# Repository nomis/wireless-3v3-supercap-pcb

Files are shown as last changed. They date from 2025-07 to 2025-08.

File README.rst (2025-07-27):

Wireless 3.3V Supercapacitor PCB
================================

Overview
--------

PCB to wirelessly power a 3.3V microcontroller circuit and charge a
supercapacitor so that it keeps running for at least an hour when taken off the
charging coil.

Dimensions: 88mm W × 40mm H

Usage
-----

This is a KiCad project.

Safety
------

There is a toggle switch to discharge the supercapacitor, which will take 14-16
minutes at 390mΩ (unverified). This process is limited by the current switching
capacity of the switch.

Schematics
----------

Root schematic

Power In
~~~~~~~~

Power in schematic

Charge
~~~~~~

Charge schematic

Power Out
~~~~~~~~~

Output power is supplied at 3.3V up to 3A, from a supercapacitor voltage range
of 0.5-2.7V.

Power out schematic

PCB
---

PCB

Components
----------

+---------------------+----------+--------------------------------------------------------------+
| Refs                | Quantity | Name                                                         |
+=====================+==========+==============================================================+
| C.C0                |     1    | 22pF 10% 16V X7R Capacitor, SMD 0805 (Metric 2012)           |
+---------------------+----------+--------------------------------------------------------------+
| C.C1, C.C6, C.10,   |     4    | 0.1µF 10% 16V X7R Capacitor, SMD 0805 (Metric 2012)          |
| C.C11               |          |                                                              |
+---------------------+----------+--------------------------------------------------------------+
| C.C4, C.C5, C.C7    |     3    | 1µF 10% 16V X7R Capacitor, SMD 0805 (Metric 2012)            |
+---------------------+----------+--------------------------------------------------------------+
| C.C8, C.C9, P.C1    |     3    | 10µF 10% 16V X7R Capacitor, SMD 0805 (Metric 2012)           |
+---------------------+----------+--------------------------------------------------------------+
| C.C12               |     1    | 15µF 10% 16V X7R Capacitor, SMD 0805 (Metric 2012)           |
+---------------------+----------+--------------------------------------------------------------+
| M.C1                |     1    | Tecate TPLH-2R7/800PS35X71 800F 2.7V Capacitor, Through Hole |
+---------------------+----------+--------------------------------------------------------------+
| P.C2, P.C2          |     2    | 22µF 10% 10V X7R Capacitor, SMD 1206 (Metric 3216)           |
+---------------------+----------+--------------------------------------------------------------+
| C.D1                |     1    | Diotec BAT54 30V 200mA Zener Diode, SOT-23-3                 |
+---------------------+----------+--------------------------------------------------------------+
| M.J1                |     1    | 1x05 Pin Header, Through Hole (2.54mm)                       |
+---------------------+----------+--------------------------------------------------------------+
| C.L1                |     1    | Bourns SRN5040-100M 10µH 20% 2.1A Power Inductor             |
+---------------------+----------+--------------------------------------------------------------+
| P.L1                |     1    | Bourns SRP1245A-1R0M 1µH 20% 29A Power Inductor              |
+---------------------+----------+--------------------------------------------------------------+
| C.Q4, C.Q5          |     2    | Vishay SiS412DN N-Channel 30V 12A MOSFET, PowerPAK 1212-8    |
+---------------------+----------+--------------------------------------------------------------+
| M.R2                |     1    | 1kΩ 1% 125mW Resistor, SMD 0805 (Metric 2012)                |
+---------------------+----------+--------------------------------------------------------------+
| C.R0                |     1    | 10mΩ 0.1% 1W Resistor, SMD 0805 (Metric 2012)                |
+---------------------+----------+--------------------------------------------------------------+
| C.R1                |     1    | 305kΩ 0.1% 125mW Resistor, SMD 0805 (Metric 2012)            |
+---------------------+----------+--------------------------------------------------------------+
| C.R2                |     1    | 86.6kΩ 0.1% 125mW Resistor, SMD 0805 (Metric 2012)           |
+---------------------+----------+--------------------------------------------------------------+
| C.R5                |     1    | 100Ω 0.1% 125mW Resistor, SMD 0805 (Metric 2012)             |
+---------------------+----------+--------------------------------------------------------------+
| C.R6                |     1    | 10Ω 1% 125mW Resistor, SMD 0805 (Metric 2012)                |
+---------------------+----------+--------------------------------------------------------------+
| C.R7                |     1    | 100kΩ 0.1% 125mW Resistor, SMD 0805 (Metric 2012)            |
+---------------------+----------+--------------------------------------------------------------+
| C.R8                |     1    | 11.1kΩ 0.1% 125mW Resistor, SMD 0805 (Metric 2012)           |
+---------------------+----------+--------------------------------------------------------------+
| P.R1                |     1    | 402kΩ 0.1% 125mW Resistor, SMD 0805 (Metric 2012)            |
+---------------------+----------+--------------------------------------------------------------+
| P.R2                |     1    | 88.7kΩ 0.1% 125mW Resistor, SMD 0805 (Metric 2012)           |
+---------------------+----------+--------------------------------------------------------------+
| P.R3, P.R4          |     2    | 10kΩ 1% 125mW Resistor, SMD 0805 (Metric 2012)               |
+---------------------+----------+--------------------------------------------------------------+
| M.SW1               |     1    | C&K E103SYZGE SPDT Toggle Switch 7.5A 125V                   |
+---------------------+----------+--------------------------------------------------------------+
| C.TH1               |     1    | 1x02 Pin Header, Through Hole (2.54mm)                       |
|                     |     1    | Semitec 103AT-4-70261 10kΩ 1% Thermistor                     |
+---------------------+----------+--------------------------------------------------------------+
| C.U1                |     1    | Texas Instruments BQ24640RVAR Super Capacitor Charger        |
+---------------------+----------+--------------------------------------------------------------+
| P.U1                |     1    | Texas Instruments TPS61022 8A Boost Converter, 0.5-5.5V      |
+---------------------+----------+--------------------------------------------------------------+
|                     |     1    | Vishay IWAS4832AEEB120KF1 Wireless Charging Receive Coil     |
+---------------------+----------+--------------------------------------------------------------+

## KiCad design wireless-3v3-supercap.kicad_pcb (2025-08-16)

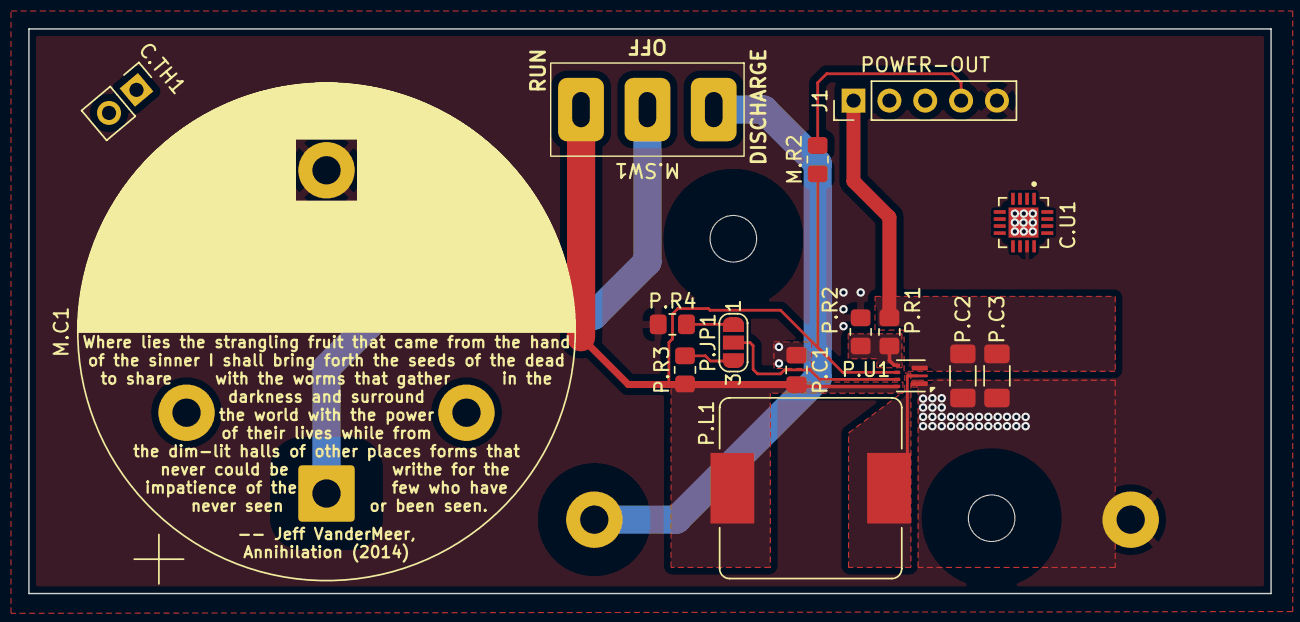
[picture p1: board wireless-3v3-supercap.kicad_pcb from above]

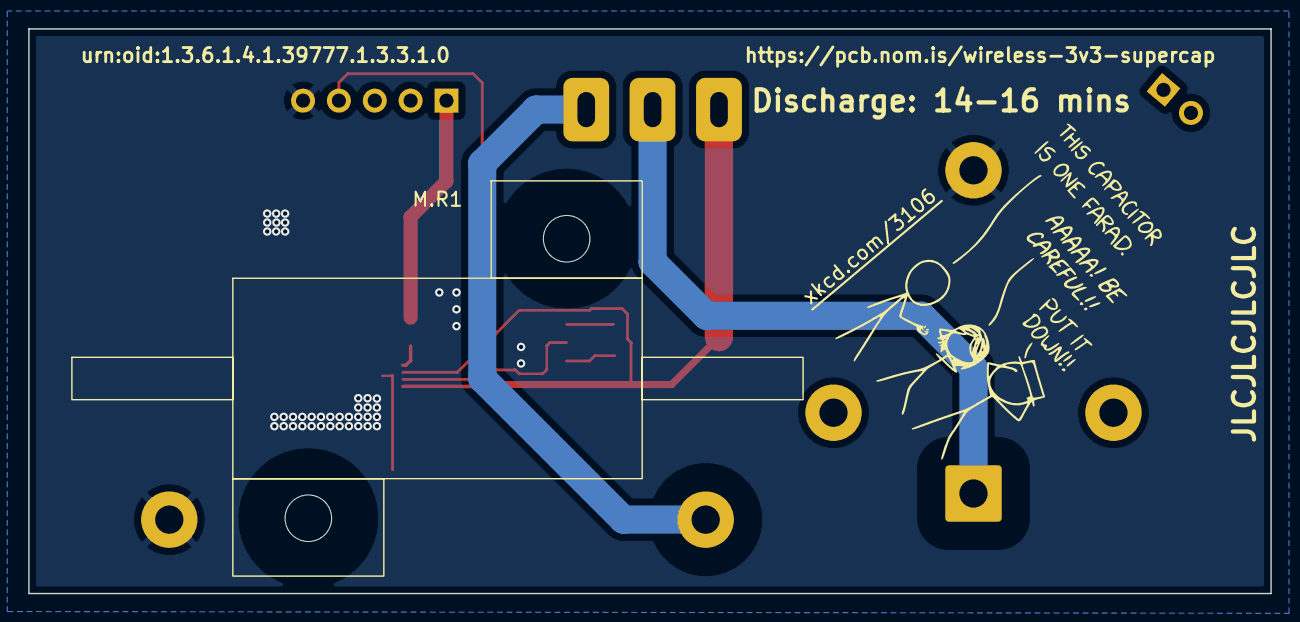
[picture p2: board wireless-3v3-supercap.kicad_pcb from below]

Board: 2 copper layers, 88.0 x 40.0 mm, 18 parts (2 on the bottom side), 14 nets.

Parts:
C.TH1: 10kΩ 1%; PinHeader_1x02_P2.54mm_Vertical
C.U1: BQ24640RVAR; QFN50P350X350X100-17N
J1: POWER-OUT; PinHeader_1x05_P2.54mm_Vertical
M.C1: 800F 2.7V; TPLH-2R7_800PS35X71
M.R1: 390mΩ 5% 25W; THS25R39J
M.R2: 1kΩ 1% 125mW; R_0805_2012Metric_Pad1.20x1.40mm_HandSolder
M.SW1: MODE; E103SYZGE
P.C1: 10µF 10% 10V X7R; C_0805_2012Metric_Pad1.18x1.45mm_HandSolder
P.C2, P.C3: 22µF 10% 10V X7R; C_1206_3216Metric_Pad1.33x1.80mm_HandSolder
P.JP1: SolderJumper_2_Open; SolderJumper-3_P1.3mm_Open_RoundedPad1.0x1.5mm_NumberLabels
P.L1: 1µH 25A 30%; L_Bourns_SRP1245A
P.R1: 402kΩ 1% 125mW; R_0805_2012Metric_Pad1.20x1.40mm_HandSolder
P.R2: 88.7kΩ 1% 125mW; R_0805_2012Metric_Pad1.20x1.40mm_HandSolder
P.R3, P.R4: 10kΩ 1% 125mW; R_0805_2012Metric_Pad1.20x1.40mm_HandSolder
P.U1: TPS61022; Texas_RWU0007A_VQFN-7_2x2mm_P0.5mm
XKCD: LOGO

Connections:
+3.3V: J1.1, P.C2.1, P.C3.1, P.R1.1, P.U1.3 (VOUT)
/Charge/SUPERCAP: M.R2.1, M.SW1.3 (4), P.C1.1, P.L1.1, P.R3.1, P.U1.5 (EN), P.U1.7 (VIN)
/DISCHARGE: M.R1.1, M.SW1.1
/Power Out/POWER_FB: P.R1.2, P.R2.1, P.U1.4 (FB)
/Power Out/POWER_SW: P.L1.2, P.U1.2 (SW)
/SUPERCAP: M.C1.1, M.SW1.2 (3)
CAPACITOR_VOLTAGE: J1.4, M.R2.2
CHARGE_STATUS: C.U1.3 (STAT), J1.3
GND: C.U1.11 (GND), C.U1.17 (EP), J1.5, M.C1.2, M.R1.2, P.C1.2, P.C2.2, P.C3.2, P.R2.2, P.R4.2, P.U1.1 (GND)
unnamed: C.U1.2 (CE), C.U1.6 (VREF)
unnamed: P.JP1.1 (A), P.R4.1
unnamed: P.JP1.3 (B), P.R3.2
unnamed: P.JP1.2 (C), P.U1.6 (MODE)
~EXTERNAL_POWER_PRESENT: C.U1.5 (~PG), J1.2

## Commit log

2025-07-11 Add a discharge switch
    [wireless-3v3-supercap.kicad_pcb, wireless-3v3-supercap.kicad_sch]
2025-07-11 Add heatsinks to the discharge resistors
    [wireless-3v3-supercap.kicad_sch]
2025-07-11 Show discharge time on the back too
    [wireless-3v3-supercap.kicad_pcb]
2025-07-11 Move power in pin header out of the way of the resistors
    [wireless-3v3-supercap.kicad_pcb]
2025-07-13 Add BQ33100PWR
    [wireless-3v3-supercap.kicad_pcb, wireless-3v3-supercap.kicad_sch]
2025-07-13 Add capacitor loss markings
    [wireless-3v3-supercap.kicad_pcb]
2025-07-13 Move pin headers further away from the edge of the PCB
    [wireless-3v3-supercap.kicad_pcb]
2025-07-13 Make discharge tracks thicker
    [wireless-3v3-supercap.kicad_pcb]
2025-07-16 Remove BQ33100PWR and discharge resistors
    [wireless-3v3-supercap.kicad_pcb, wireless-3v3-supercap.kicad_sch]
2025-07-16 Resize PCB to available space
    [wireless-3v3-supercap.kicad_pcb]
2025-07-16 Add discharge circuit, and main component for charging/power out
    [charge.kicad_sch, power-in.kicad_sch, power-out.kicad_sch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]
2025-07-16 Configure power output
    [power-out.kicad_sch, wireless-3v3-supercap.kicad_pcb]
2025-07-17 Add power output capacitors
    [power-out.kicad_sch, wireless-3v3-supercap.kicad_pcb, wireless-3v3-supercap.kicad_sch]
2025-07-17 Add inductor and finish power out layout
    [power-out.kicad_sch, wireless-3v3-supercap.kicad_pcb, wireless-3v3-supercap.kicad_sch]
2025-07-17 Use 1mm traces for 3.3V power output
    [wireless-3v3-supercap.kicad_pcb]
2025-07-17 Fix schematic links
2025-07-17 Update components list
    [charge.kicad_sch]
2025-07-17 Add 3D model for the TPS61022
    [wireless-3v3-supercap.kicad_pcb]
2025-07-18 Prefix all of the references so that the numbering is manageable across multiple circuits
    [charge.kicad_sch, power-in.kicad_sch, power-out.kicad_sch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]
2025-07-18 Remove charge enable pin
    [charge.kicad_sch, wireless-3v3-supercap.kicad_pcb, wireless-3v3-supercap.kicad_sch]
2025-07-18 Connect charger CE to VREF, not VCC
    [charge.kicad_sch, wireless-3v3-supercap.kicad_pcb]
2025-07-20 Add voltage divider circuit for ADC
    [power-out.kicad_sch, wireless-3v3-supercap.kicad_pcb, wireless-3v3-supercap.kicad_sch]
2025-07-20 Fix MOSFET for measuring capacitor voltage
    [wireless-3v3-supercap.kicad_pcb, wireless-3v3-supercap.kicad_sch]
2025-07-20 Mark signals as active low
    [charge.kicad_sch, wireless-3v3-supercap.kicad_pcb, wireless-3v3-supercap.kicad_sch]
2025-07-20 Adjust ADC voltage divider
    Increase the value of the 0.5V minimum voltage reading to improve accuracy
    [wireless-3v3-supercap.kicad_pcb, wireless-3v3-supercap.kicad_sch]
2025-07-21 Remove voltage divider circuit for ADC
    The ESP32-C3 can be configured to handle this directly
    [wireless-3v3-supercap.kicad_pcb, wireless-3v3-supercap.kicad_sch]
2025-07-21 Fix pin header name and size
    [wireless-3v3-supercap.kicad_pcb, wireless-3v3-supercap.kicad_sch]
2025-07-22 Add xkcd comic
    [wireless-3v3-supercap.kicad_pcb]
2025-07-23 Add incomplete charge circuit
    [charge.kicad_sch, power-out.kicad_sch, wireless-3v3-supercap.kicad_pcb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]
2025-07-27 Finish charge circuit
    [charge.kicad_sch, power-out.kicad_sch]
2025-07-27 Center charge schematic
    [charge.kicad_sch]
2025-07-27 Add PCB OID and URL
    [wireless-3v3-supercap.kicad_pcb]
2025-07-27 Add JLC order number text
    [wireless-3v3-supercap.kicad_pcb]
2025-07-30 Add Area X crawler text quote underneath the topographical anomaly
    [wireless-3v3-supercap.kicad_pcb]
2025-08-16 Update footprint of THS25R39J
    This measures L=27.3mm M=44.8mm which is much smaller than the maximum
    documented size. Retain the original sizes but move the pads closer
    together to match the connection holes.
    [wireless-3v3-supercap.kicad_pcb]
2025-08-16 Update footprint of E013SYZGE
    Contacts are 2.1mm wide
    [wireless-3v3-supercap.kicad_pcb]
